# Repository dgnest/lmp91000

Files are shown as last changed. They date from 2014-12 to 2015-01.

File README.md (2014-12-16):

# Using the LMP91000 gas sensor with Arduino

The LMP91000 is a programmable Analog Front End (AFE) for use in micro-power electrochemical sensing applications... [+ info about it](http://www.ti.com/product/lmp91000 "more info")

He we use this great gas sensor alongside an Arduino Mega 2560.

[datasheet](http://www.ti.com/lit/ds/symlink/lmp91000.pdf "datasheet")

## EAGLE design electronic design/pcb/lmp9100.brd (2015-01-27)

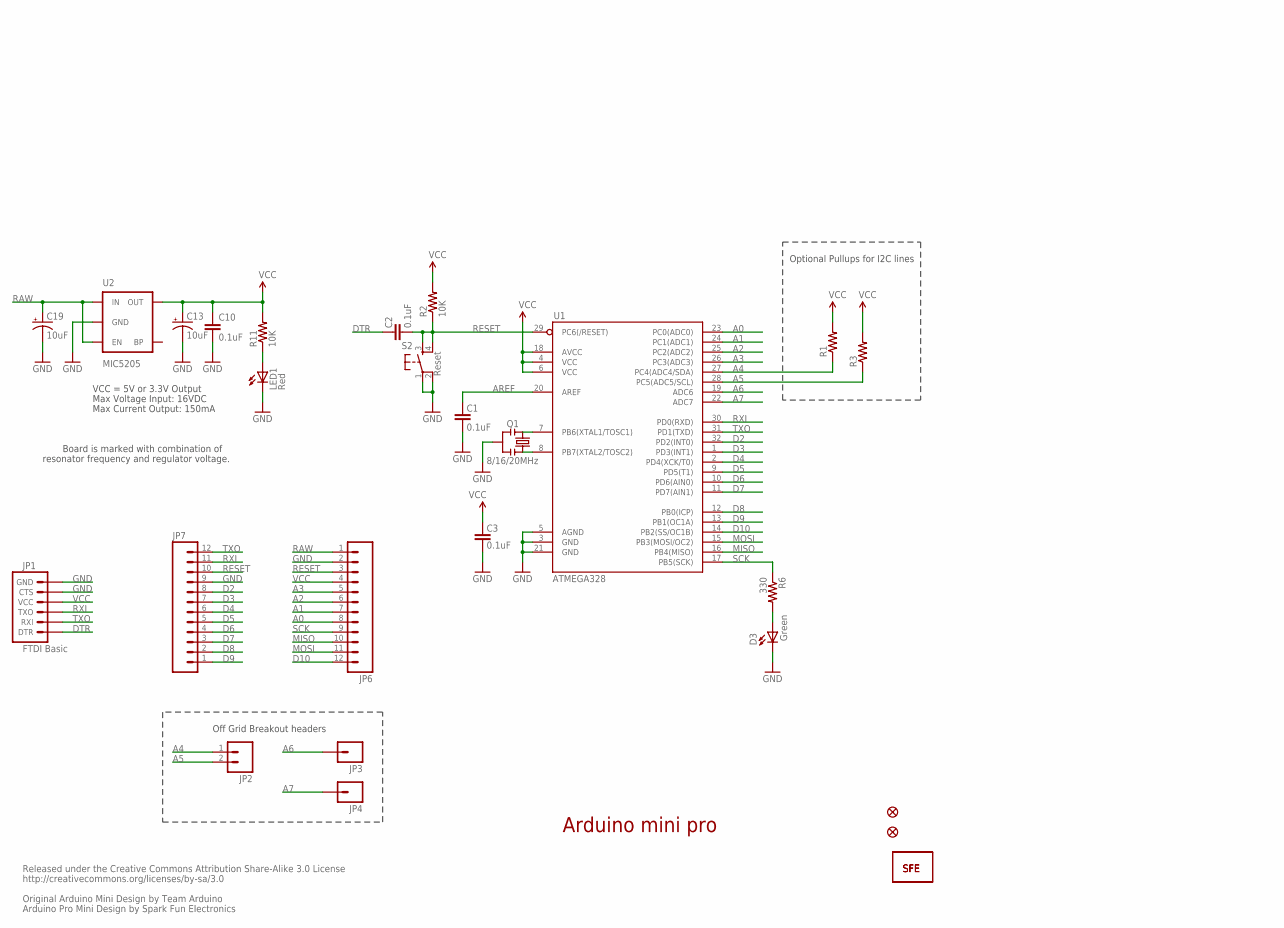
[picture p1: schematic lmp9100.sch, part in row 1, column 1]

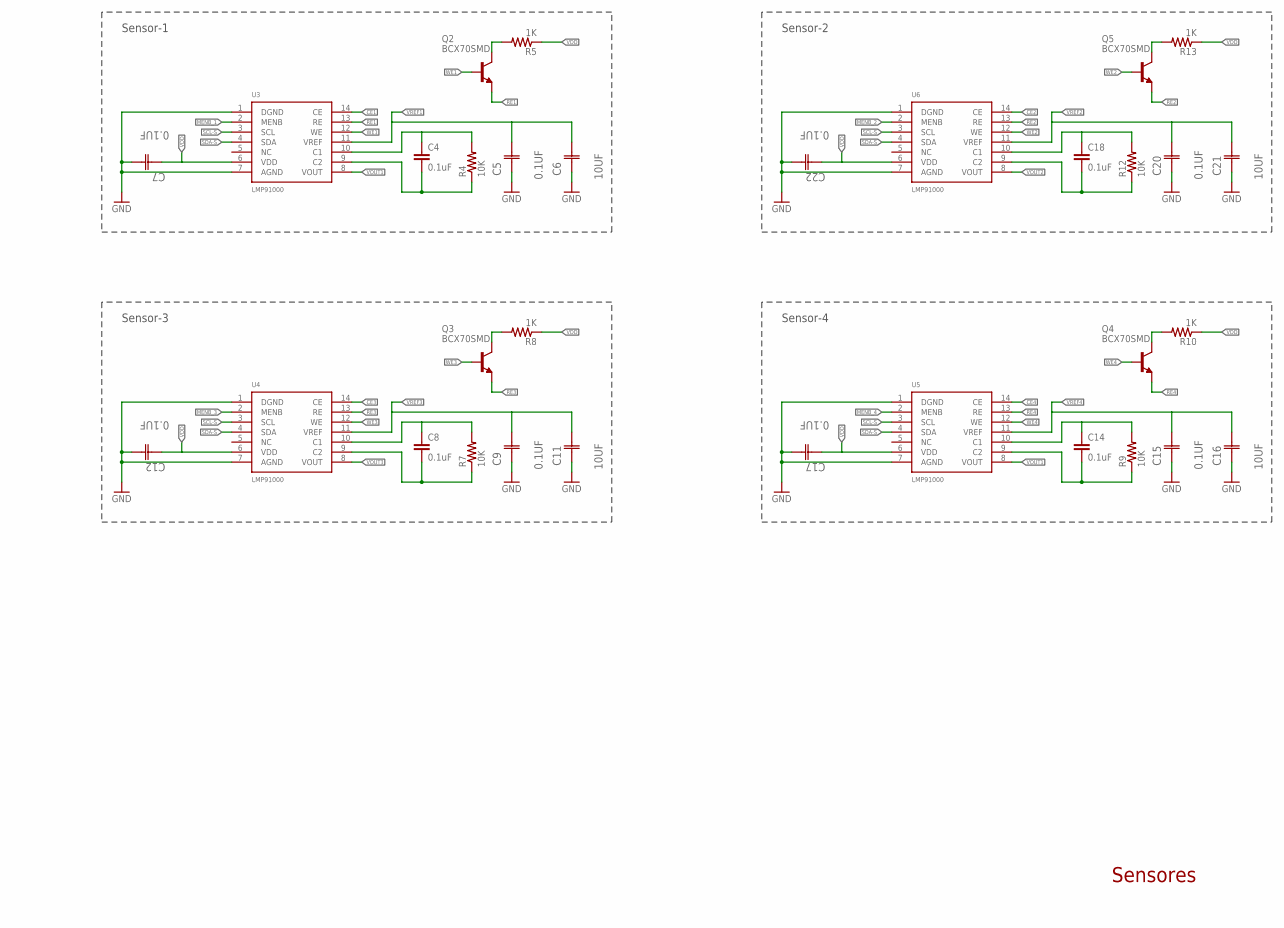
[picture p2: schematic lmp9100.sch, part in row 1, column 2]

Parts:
C1, C2, C3, C4, C8, C10, C14, C18: 0.1uF; 0402-CAP
C5, C7, C9, C12, C15, C17, C20, C22: 0.1UF; CAPC1608X90N
C6, C11, C16, C21: 10UF; CAPC3216X178N
C13, C19: 10uF; EIA3216
D3: Green; LED-0603
JP1: FTDI Basic; 1X06
JP2: M02PTH; 1X02
JP3, JP4: M01PTH; 1X01
JP5, JP8: FIDUCIALUFIDUCIAL; MICRO-FIDUCIAL
JP6, JP7: M12PTH; 1X12
LED1: Red; LED-0603
Q1: 8/16/20MHz; RESONATOR-SMD
Q2, Q3, Q4, Q5: BCX70SMD; SOT23
R1, R3: RESISTOR0402-RES; 0402-RES
R2, R4, R7, R9, R11, R12: 10K; 0402-RES
R5, R8, R10, R13: 1K; 0402-RES
R6: 330; 0402-RES
S2: Reset; TACTILE_SWITCH_SMD
U1: ATMEGA328; TQFP32-08
U2: MIC5205; SOT23-5
U3, U4, U5, U6: LMP91000
U$1: LOGO-SFESK; SFE-LOGO-FLAME
U$11: LOGO-SFENEW; SFE-NEW-WEBLOGO

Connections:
A0: JP6.8, U1.23 (PC0(ADC0))
A1: JP6.7, U1.24 (PC1(ADC1))
A2: JP6.6, U1.25 (PC2(ADC2))
A3: JP6.5, U1.26 (PC3(ADC3))
A4: JP2.1, R1.1, U1.27 (PC4(ADC4/SDA))
A5: JP2.2, R3.1, U1.28 (PC5(ADC5/SCL))
A6: JP3.1, U1.19 (ADC6)
A7: JP4.1, U1.22 (ADC7)
AREF: C1.2, U1.20 (AREF)
CE1: U3.14 (CE)
CE2: U6.14 (CE)
CE3: U4.14 (CE)
CE4: U5.14 (CE)
D2: JP7.8, U1.32 (PD2(INT0))
D3: JP7.7, U1.1 (PD3(INT1))
D4: JP7.6, U1.2 (PD4(XCK/T0))
D5: JP7.5, U1.9 (PD5(T1))
D6: JP7.4, U1.10 (PD6(AIN0))
D7: JP7.3, U1.11 (PD7(AIN1))
D8: JP7.2, U1.12 (PB0(ICP))
D9: JP7.1, U1.13 (PB1(OC1A))
D10: JP6.12, U1.14 (PB2(SS/OC1B))
DTR: C2.2, JP1.1 (DTR)
GND: C1.1, C3.1, C5.1 (C1), C6.1 (C1), C7.2 (C2), C9.1 (C1), C10.2, C11.1 (C1), C12.2 (C2), C13.C (-), C15.1 (C1), C16.1 (C1), C17.2 (C2), C19.C (-), C20.1 (C1), C21.1 (C1), C22.2 (C2), D3.C, JP1.5 (CTS), JP1.6 (GND), JP6.2, JP7.9, LED1.C, Q1.2, S2.1, S2.2, U1.3 (GND), U1.5 (AGND), U1.21 (GND), U2.2 (GND), U3.1 (DGND), U3.7 (AGND), U4.1 (DGND), U4.7 (AGND), U5.1 (DGND), U5.7 (AGND), U6.1 (DGND), U6.7 (AGND)
MENB_1: U3.2 (MENB)
MENB_2: U6.2 (MENB)
MENB_3: U4.2 (MENB)
MENB_4: U5.2 (MENB)
MISO: JP6.10, U1.16 (PB4(MISO))
MOSI: JP6.11, U1.15 (PB3(MOSI/OC2))
unnamed: Q1.1, U1.8 (PB7(XTAL2/TOSC2))
unnamed: Q1.3, U1.7 (PB6(XTAL1/TOSC1))
unnamed: C4.2, R4.1, U3.9 (C2)
unnamed: C4.1, R4.2, U3.10 (C1)
unnamed: Q2.3 (C), R5.2
unnamed: C8.2, R7.1, U4.9 (C2)
unnamed: D3.A, R6.2
unnamed: C8.1, R7.2, U4.10 (C1)
unnamed: Q3.3 (C), R8.2
unnamed: C14.2, R9.1, U5.9 (C2)
unnamed: C14.1, R9.2, U5.10 (C1)
unnamed: Q4.3 (C), R10.2
unnamed: C18.2, R12.1, U6.9 (C2)
unnamed: C18.1, R12.2, U6.10 (C1)
unnamed: Q5.3 (C), R13.2
unnamed: LED1.A, R11.1
RAW: C19.A (+), JP6.1, U2.1 (IN), U2.3 (EN)
RE1: Q2.2 (E), U3.13 (RE)
RE2: Q5.2 (E), U6.13 (RE)
RE3: Q3.2 (E), U4.13 (RE)
RE4: Q4.2 (E), U5.13 (RE)
RESET: C2.1, JP6.3, JP7.10, R2.1, S2.3, S2.4, U1.29 (PC6(/RESET))
RXI: JP1.3 (TXO), JP7.11, U1.30 (PD0(RXD))
SCK: JP6.9, R6.1, U1.17 (PB5(SCK))
SCL-S: U3.3 (SCL), U4.3 (SCL), U5.3 (SCL), U6.3 (SCL)
SDA-S: U3.4 (SDA), U4.4 (SDA), U5.4 (SDA), U6.4 (SDA)
TXO: JP1.2 (RXI), JP7.12, U1.31 (PD1(TXD))
VCC: C3.2, C10.1, C13.A (+), JP1.4 (VCC), JP6.4, R1.2, R2.2, R3.2, R11.2, U1.4 (VCC), U1.6 (VCC), U1.18 (AVCC), U2.5 (OUT)
VDD: C7.1 (C1), C12.1 (C1), C17.1 (C1), C22.1 (C1), R5.1, R8.1, R10.1, R13.1, U3.6 (VDD), U4.6 (VDD), U5.6 (VDD), U6.6 (VDD)
VOUT1: U3.8 (VOUT), U5.8 (VOUT)
VOUT2: U6.8 (VOUT)
VOUT3: U4.8 (VOUT)
VREF1: C5.2 (C2), C6.2 (C2), U3.11 (VREF)
VREF2: C20.2 (C2), C21.2 (C2), U6.11 (VREF)
VREF3: C9.2 (C2), C11.2 (C2), U4.11 (VREF)
VREF4: C15.2 (C2), C16.2 (C2), U5.11 (VREF)
WE1: Q2.1 (B), U3.12 (WE)
WE2: Q5.1 (B), U6.12 (WE)
WE3: Q3.1 (B), U4.12 (WE)
WE4: Q4.1 (B), U5.12 (WE)

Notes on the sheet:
Released under the Creative Commons Attribution Share-Alike 3.0 License
http://creativecommons.org/licenses/by-sa/3.0
Original Arduino Mini Design by Team Arduino
Arduino Pro Mini Design by Spark Fun Electronics
Max Voltage Input: 16VDC
Max Current Output: 150mA
Board is marked with combination of
resonator frequency and regulator voltage.
VCC = 5V or 3.3V Output
Optional Pullups for I2C lines
Off Grid Breakout headers
Sensor-1
Sensor-3
Sensor-4
Sensor-2
Sensores
Arduino mini pro

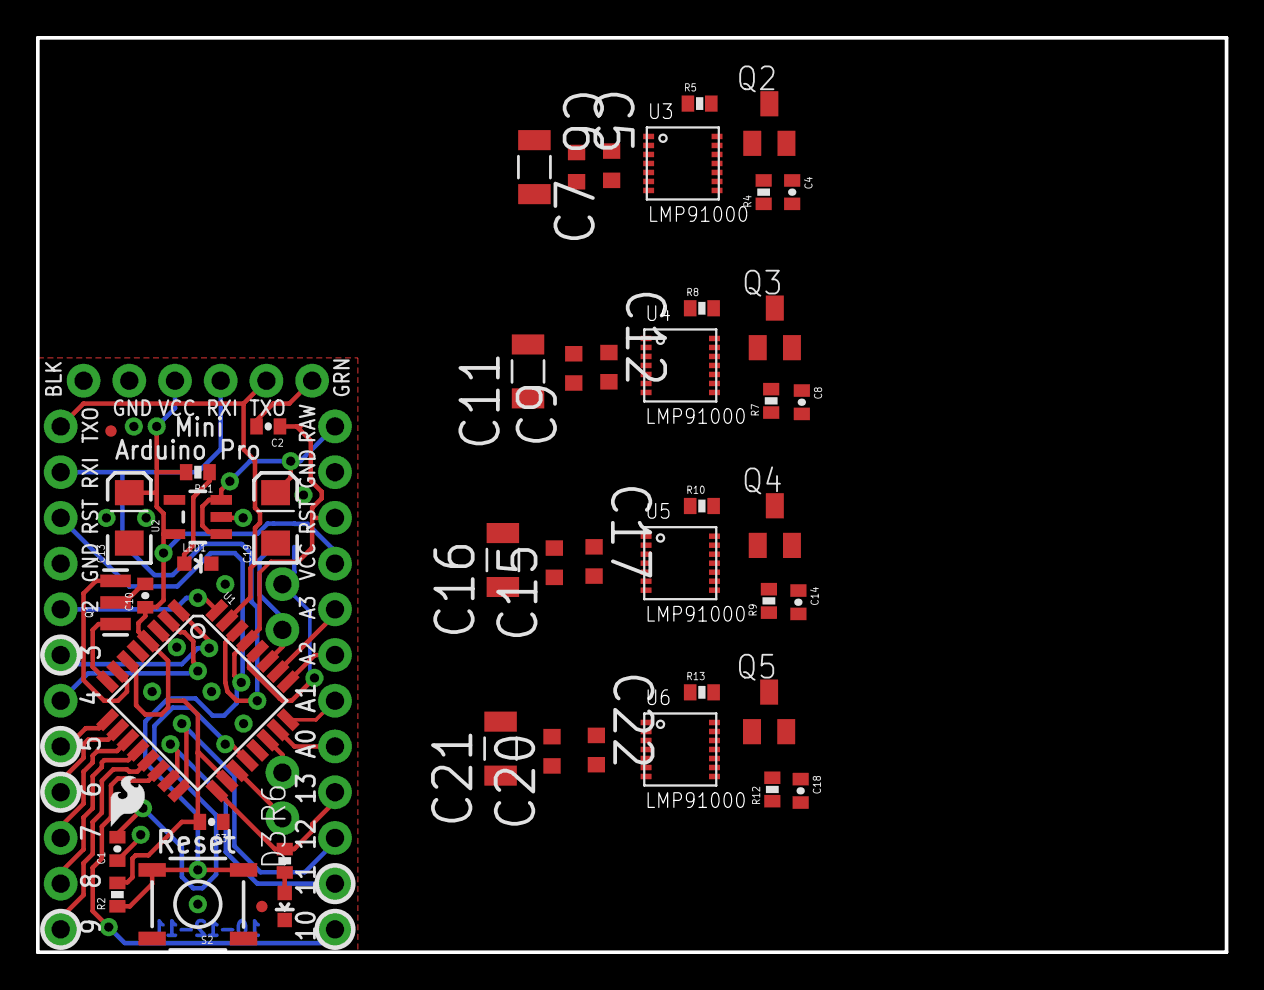
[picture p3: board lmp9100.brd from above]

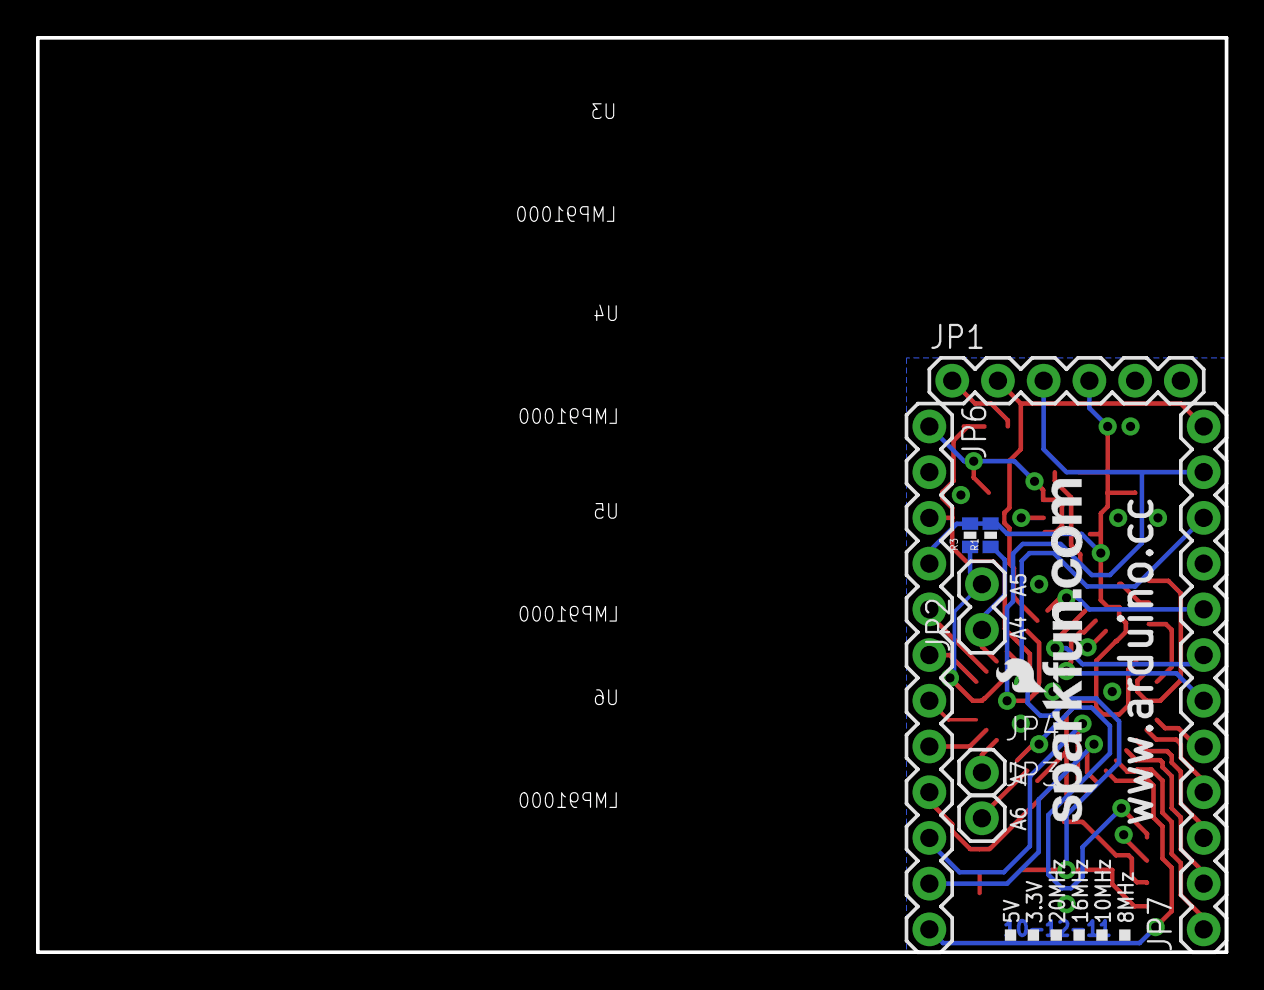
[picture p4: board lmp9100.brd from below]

Board: 2 copper layers, 66.0 x 50.8 mm, 59 parts (9 on the bottom side), 60 nets.

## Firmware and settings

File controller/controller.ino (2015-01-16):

#include <Wire.h>
#include <StandardCplusplus.h>
#include <vector>

#include "Frame.h"
#include "lmp91000.h"

using namespace std;


vector<byte> input_frame;
boolean processed_frame = false;

byte frame_byte;
int frame_counter = 0;

// The frame has the following structure.
// [Start('S'), option, id, address, value, Stop('\n')]
Frame frame;
GasSensor sensor;

GasSensor sensor0(0, 10);
GasSensor sensor1(1, 11);
GasSensor sensor2(2, 12);
GasSensor sensor3(3, 13);

void setup() {
  Serial.begin(9600);
  Wire.begin();
}

void loop() {
  // Enters if the whole frame arrives.
  if (processed_frame) {
    frame.set_frame(input_frame);

    frame.parseFrame();

    Serial.print(frame.option());
    Serial.print("-");
    Serial.print(frame.id(), HEX);
    Serial.print("-");
    Serial.print(frame.address(), HEX);
    Serial.print("-");
    Serial.print(frame.value(), HEX);
    Serial.print(":");
    Serial.print(":");

    // Maps sensor.
    switch (frame.id()) {
      case 0:
        sensor = sensor1;
        break;
      case 1:
        sensor = sensor1;
        break;
      case 2:
        sensor = sensor2;
        break;
      case 3:
        sensor = sensor3;
        break;
    }

    switch (frame.option()) {
      case 'w':
        sensor.writeRegister(frame.address(), frame.value());
        Serial.println('w');
        break;
      case 'r':
        Serial.print(sensor.readRegister(frame.address()), HEX);
        Serial.print("-");
        Serial.println('r');
        break;
      case 'a':
        Serial.println('a');
        break;
    }

    processed_frame = false;
  }
}

void serialEvent() {
  while (Serial.available() > 0) {
    frame_byte = (byte)Serial.read();
    if (frame_byte == Frame::kStartFrame || frame_counter > 0) {
      frame_counter++;
      input_frame.push_back(frame_byte);
      if (frame_counter == Frame::kFrameLength) {
        processed_frame = true;
        frame_counter = 0;
      }
    }
  }
}

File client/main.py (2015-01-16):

import serial
import time
import sys

from serialport import get_open_port


def setup():
    port = get_open_port()
    ser = serial.Serial(port, 9600, timeout=1)
    time.sleep(2)
    return ser

def send_cmd(cmd):
    ser.write(cmd + "E")
    line = ser.readline()
    print line


if __name__ == '__main__':
    ser = setup()
    while True:
        cmd = raw_input(
            "Enter commands [w:write / r:read / a:read analog data / q:quit]: "
        )
        if cmd == 'r':
            # Send Init + command bytes.
            ser.write("Sr")
            # Sensor id.
            ser.write(chr(1))
            # Address.
            ser.write(chr(0x10))
            # Value.
            ser.write(chr(0x00))
            # Send stop byte.
            ser.write("E")
        if cmd == 'w':
            # send_cmd('Sw045')

            # Send Init + command bytes.
            ser.write('S')
            ser.write('w')
            # Sensor id.
            ser.write(chr(1))
            # Address.
            ser.write(chr(0x10))
            # Value.
            ser.write(chr(0xFF))
            # Send stop byte
            ser.write('E')
        if cmd == 'a':
            send_cmd('Sa01f')
        if cmd == 'q':
            break
        
        line = ser.readline()
        print line
    try:
        ser.close()
        print "\nPort closed. Bye..."
    except:
        print "\nPort couldn't be closed!"

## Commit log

2014-12-16 add arduino source file, readme and an empty gitignore :)
2015-01-08 change arduino's source files scaffolding
2015-01-09 create frame.h library. Refactor controller.ino
2015-01-11 refactoring Frame library
2015-01-11 send frame with valid options
2015-01-11 refactor frame libray. Add new library to handle the sensor: lm91000
2015-01-15 add readRegister method and hardcode to send a fixed register
    [controller.ino, lmp91000.cpp]
2015-01-27 add electronic design
    [lmp9100.brd, lmp9100.sch]
